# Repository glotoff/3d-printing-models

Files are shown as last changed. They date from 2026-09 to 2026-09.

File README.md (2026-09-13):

# Modular Single-Bay HDD / SSD Caddy (70mm Tall, +10mm Ventilation, Split Guide Pins)

A modular, linkable 3D-printable dock tailored specifically for **$78\text{ mm} \times 14\text{ mm}$ external hard drive / SSD enclosures**, featuring an expanded **$+10\text{ mm}$ ventilation clearance** with **4 internal split cylinder guide pins (7 mm bottom + 7 mm top)** that rigidly constrain the drive while maximizing airflow and reducing print time and plastic consumption.

| Hard Drive Enclosure in Dock (+5mm Air Gap) | 4 Cylinder Pins Inside Bay | 100% Flat Mating Exterior |
| :---: | :---: | :---: |
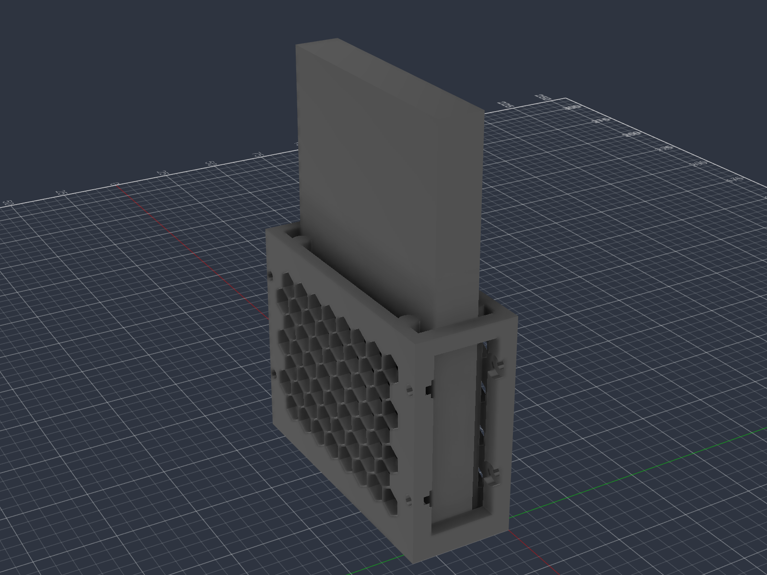
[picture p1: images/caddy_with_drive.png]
Caddy with Drive
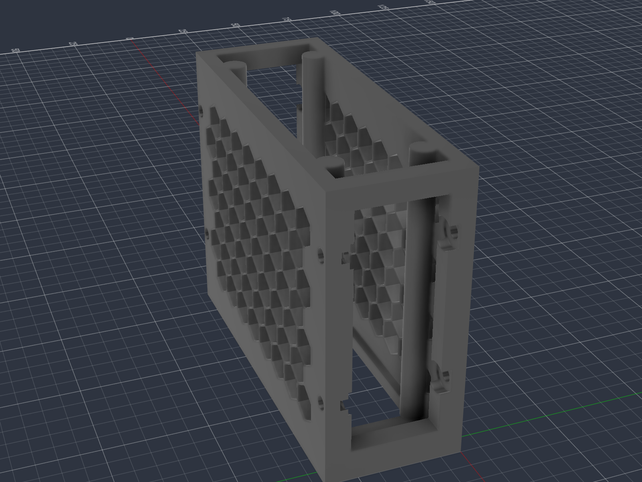
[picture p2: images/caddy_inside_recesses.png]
4 Cylinder Pins Inside
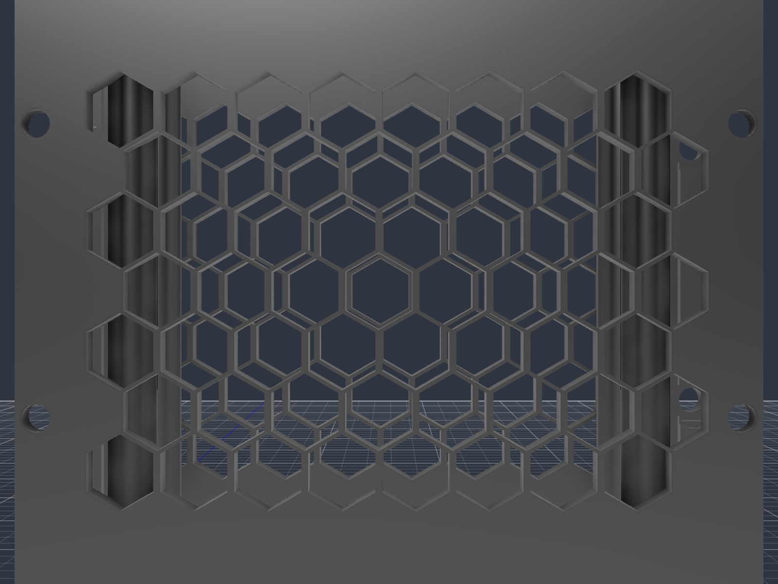
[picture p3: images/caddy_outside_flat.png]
Outside Flat Face
|  |  |  |

---

## Key Features

1. **+10 mm Ventilation Expansion with Split Guide Pins (7 mm Bottom + 7 mm Top):**
   - **Total Slot Width:** Expanded from $14.8\text{ mm}$ to **$24.8\text{ mm}$** (+10 mm) for unrestricted airflow.
   - **Split Cylinder Guide Pins ($\varnothing 6.0\text{ mm}$):**
     - **Bottom Pins:** $7.0\text{ mm}$ tall rising from the floor ($Z = 3.5\text{ mm}$ to $10.5\text{ mm}$) to locate and seat the base of the drive.
     - **Top Pins:** $7.0\text{ mm}$ tall at the top rim ($Z = 63.0\text{ mm}$ to $70.0\text{ mm}$) to guide drive entry and prevent top wobble.
     - **Open Midsection:** The entire middle $52.5\text{ mm}$ is completely open air, cutting print time down to **1h 18m** and filament down to **36.5 g**.
   - **Zero-Wobble Drive Constraint:** The inner tangent distance between the left and right pins is precisely **$14.8\text{ mm}$** ($0.4\text{ mm}$ clearance on each side of the $14.0\text{ mm}$ drive).
   - **Generous 5.0 mm Air Gap on Both Sides:** Rather than resting flush against the honeycomb walls, the drive is held centered with a continuous **$5.0\text{ mm}$ air gap on each side**, allowing massive cross-ventilation across both large aluminium/plastic drive surfaces.

2. **Internal Fastening System (Inside Washer & Nut Recesses):**
   - **Screw Head & Washer Seat (Left Pillar):** $\varnothing 7.5\text{ mm}$ circular counterbore ($2.5\text{ mm}$ deep) on the **inside** face of the pillar ($Y = 6.0\text{ mm}$). Fits standard DIN 125 M3 washers ($\varnothing 7.0\text{ mm}$) and socket/button head screws completely flush inside the vertical window opening.
   - **Captive Hex Nut Pocket (Right Pillar):** $5.6\text{ mm}$ across flats ($2.6\text{ mm}$ deep) with washer recess ($0.8\text{ mm}$ deep) on the **inside** face ($Y = 26.8\text{ mm}$).
   - **100% Flat Exterior Mating Faces:** Both outside walls ($Y = 0$ and $Y = 32.8\text{ mm}$) have **zero counterbores** — only clean $\varnothing 3.4\text{ mm}$ through-holes. When modules are joined side-by-side, their exterior walls mate completely flush with zero gap.
   - **Internal Assembly:** All screws, washers, and nuts are inserted and tightened from **inside** each bay.

3. **Optimized Cross-Ventilation:**
   - Full-height isometric honeycomb lattice (7 rows, 38 mm cell diagonal) on both large side walls for passive cross-ventilation.
   - Bottom chimney through-floor vent ($63.0 \times 20.8\text{ mm}$) for natural convective vertical airflow.

---

## Dimensions Summary

| Parameter | Drive Size | Internal Slot / Pins | External Footprint | Clearance / Tolerance |
| :--- | :---: | :---: | :---: | :--- |
| **Length (X axis)** | **$78.0\text{ mm}$** | **$79.0\text{ mm}$** | **$89.0\text{ mm}$** | $+0.5\text{ mm}$ per end ($1.0\text{ mm}$ total) for smooth insertion |
| **Width / Depth (Y axis)** | **$14.0\text{ mm}$** | **$24.8\text{ mm}$ slot**<br>($14.8\text{ mm}$ between pins) | **$32.8\text{ mm}$** | $+0.4\text{ mm}$ per side between pins; **$5.0\text{ mm}$ air gap** to each wall |
| **Height (Z axis)** | ~125 mm | Open top | **$70.0\text{ mm}$** | High lateral stability |
| **Side Wall Thickness** | — | — | **$4.0\text{ mm}$** | Solid perimeters (4 wall loops) |
| **Floor Thickness** | — | — | **$3.5\text{ mm}$** | Rigid base with chimney vent |
| **Guide Pins** | — | **$4 \times \varnothing 6.0\text{ mm}$ (Split)** | — | **$7.0\text{ mm}$ bottom** + **$7.0\text{ mm}$ top** |
| **Mounting Levels** | — | — | **$Z = 20\text{ mm}$, $Z = 55\text{ mm}$** | Dual screw rigidity |

---

## Multi-Bay Stacking Guide

Modules are daisy-chained side-by-side:

```
       [Bay 1]                  [Bay 2]
+--------------------+   +--------------------+
|  (Inside Bay 1)    |   |  (Inside Bay 2)    |
|                    |   |                    |
|  [Screw + Washer]  |   |    [M3 Hex Nut]    |
|         |          |   |          ^         |
|         +==========>===>==========+         |
|         4mm wall   |   |   4mm wall         |
+--------------------+   +--------------------+
     Flat Mating Joint: 8mm total solid plastic
```

1. Align the flat right exterior wall of Bay 1 with the flat left exterior wall of Bay 2.
2. From **inside Bay 1**, pass an M3 screw with an M3 washer through the inside counterbore.
3. In **inside Bay 2**, thread the screw into the captive M3 hex nut.
4. Tighten with a hex key from inside Bay 1. Both screw head and nut are recessed flush inside the respective window frames, leaving the drive pocket completely clear!

---

## Bill of Materials (BOM) per Joint

To connect two adjacent bays:
- **$2 \times$ M3 Screws:** M3 $\times 12\text{ mm}$ or M3 $\times 14\text{ mm}$ (Socket head DIN 912 or Button head ISO 7380)
- **$2 \times$ M3 Washers:** DIN 125A ($\varnothing 7.0\text{ mm}$ OD, $0.5\text{ mm}$ thickness)
- **$2 \times$ M3 Hex Nuts:** DIN 934 ($5.5\text{ mm}$ across flats)

---

## Slicer & Print Guidelines

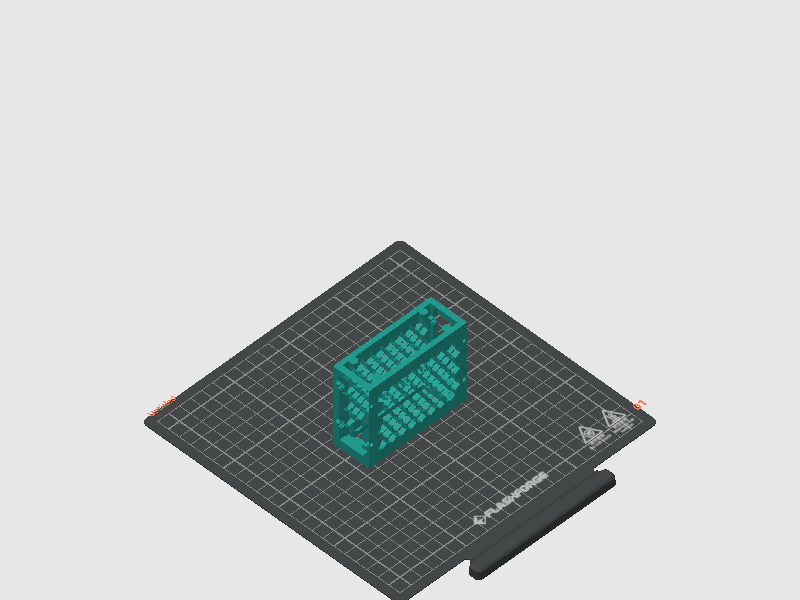
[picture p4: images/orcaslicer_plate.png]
OrcaSlicer Bed Layout


- **Printer:** Flashforge Adventurer 5M Pro / Bambu Lab / Prusa (or any FDM printer)
- **Nozzle:** $0.4\text{ mm}$
- **Layer Height:** $0.20\text{ mm}$
- **Wall Loops:** **4** (ensures 100% solid perimeters through the 4.0 mm walls, guide pins, and around screw holes)
- **Top / Bottom Shells:** 4 layers
- **Infill:** $15\text{--}20\%$ Gyroid
- **Supports:** **None required** (honeycombs, vertical pins, and bridges are 100% self-supporting)
- **Print Time:** ~1h 36m
- **Filament Consumption:** ~43.2 g

---

## Change Tracking in Git (Code-CAD)

Binary 3D models (`.stl`, `.3mf`, `.f3d`) cannot be diffed cleanly in Git. This repository provides text-based parametric models that allow full **Git change tracking**:

1. **OpenSCAD (`cad/modular_single_bay_70mm.scad`):**
   - Pure text-based CSG script.
   - All dimensions (`drive_w`, `drive_t`, `slot_l`, `slot_t`, `caddy_h`, `pin_r`, etc.) are declared as parametric variables at the top of the file.
   - Any modification will produce clear, line-by-line `git diff` outputs.
2. **Fusion 360 Python Generator (`cad/generate_fusion360_model.py`):**
   - Standalone Python script for the Fusion 360 API.
   - Fully parametric generation, appearance assignment, and automated export to STL.
3. **Fusion MCP Client (`cad/fusion_client.py`):**
   - Lightweight JSON-RPC client to execute scripts and export models directly via Fusion 360 MCP.

---

---

## Print Monitoring & Web Dashboard

This repository includes real-time telemetry tools to monitor Flashforge Adventurer 5M series printers via TCP socket (port 8899) and live MJPEG chamber camera stream (port 8080).

### 1. CLI Monitor (`print_status.py`)
Quick command-line tool for checking temperatures, layer count, file, and progress:
```bash
python print_status.py          # One-time status snapshot
python print_status.py --watch  # Auto-refreshing terminal HUD (every 5s)
```

### 2. Real-Time Web Dashboard (`app/`)
A responsive dark-themed dashboard containerized with Docker and deployed to `kopilka:4000`:
- **Live Chamber Camera Feed:** Embedded low-latency MJPEG stream with real-time XYZ toolhead coordinate overlay.
- **WebSocket Telemetry:** Zero-latency updates for Nozzle & Bed temperatures (actual vs. target), layer progress (`Layer X / Y`), elapsed time, and extruded filament length (A).
- **Printer Controls:** Remote chamber LED light toggle (`~M651` / `~M652`) and Pause / Resume controls (`~M25` / `~M24`).
- **Stream Recording & Archive:** Direct server-side recording of the camera feed into compressed H.264 MP4 clips via FFmpeg, with a built-in gallery for downloads and management.
- **Access:** Available on local network at `http://kopilka:4000/`.

To run locally or deploy:
```bash
cd app
docker compose up -d --build
```

---

---

## Fresh Laptop Setup Guide (Zero to Ready)

If you clone this repository onto a brand-new computer, here is exactly what to install and how to work with the project files:

### 1. Requirements Checklist

| Software / Tool | Purpose | How to Get |
| :--- | :--- | :--- |
| **Git** | Cloning & updating the repository | [git-scm.com](https://git-scm.com/) |
| **Python 3.10+** | CLI telemetry scripts & running the local web app | [python.org](https://www.python.org/) or `winget install Python.Python.3.12` |
| **OrcaSlicer (v2.x+)** | Slicing models & sending prints to Flashforge / Klipper | [github.com/SoftFever/OrcaSlicer/releases](https://github.com/SoftFever/OrcaSlicer/releases) |
| **Autodesk Fusion 360** *(Optional for CAD editing)* | Inspecting or modifying the native parametric model | [autodesk.com/products/fusion-360](https://www.autodesk.com/products/fusion-360/personal) |
| **Docker Desktop** *(Optional for telemetry web dashboard)* | Containerized web dashboard deployment | [docker.com](https://www.docker.com/) |

---

### 2. Workflow: 3D Printing (Ready Out of the Box)

You do **not** need CAD software installed just to slice or print:

1. **Clone the repository:**
   ```bash
   git clone https://github.com/glotoff/3d-printing-models.git
   cd 3d-printing-models
   ```
2. **Open in OrcaSlicer:**
   - Double-click [`Modular_SingleBay_16mm_M3.3mf`](Modular_SingleBay_16mm_M3.3mf).
   - This opens the exact project with all tuned print settings:
     - 4 wall loops (1.6 mm solid shell)
     - 15% infill
     - 0.20 mm layer height
     - Flashforge Adventurer 5M Pro profile
   - Click **Slice plate** and send directly to your printer over Wi-Fi.
3. **Alternatively, use the pre-sliced G-code directly:**
   - [`Modular_SingleBay_SplitPins_7mm_PLA_1h18m.gcode`](Modular_SingleBay_SplitPins_7mm_PLA_1h18m.gcode) can be loaded directly onto a USB stick or uploaded via Flashforge web UI.

---

### 3. Workflow: CAD Modeling & Editing in Autodesk Fusion 360

If you want to edit, customize, or export variations in Fusion 360:

#### Option A: Open the Standalone `.f3d` Archive (Easiest)
1. Open **Autodesk Fusion 360**.
2. Click **File** $\to$ **Open...** $\to$ **Open from my computer**.
3. Select [`cad/Modular_SingleBay_Vent10mm_SplitPins.f3d`](cad/Modular_SingleBay_Vent10mm_SplitPins.f3d).
4. All bodies (caddy body and hard drive reference mock-up) and geometry will load natively.

#### Option B: Import the Universal `.step` File
- In Fusion 360 (or FreeCAD / SolidWorks), go to **File** $\to$ **Open** $\to$ select [`cad/Modular_SingleBay_Vent10mm_SplitPins.step`](cad/Modular_SingleBay_Vent10mm_SplitPins.step).

#### Option C: Re-generate From Python Script (Parametric Automation)
1. In Fusion 360, press **Shift + S** to open the **Scripts and Add-Ins** window.
2. Under the **Scripts** tab, click the green **+** icon (Create / Add).
3. Select or paste the contents of [`cad/generate_fusion360_model.py`](cad/generate_fusion360_model.py).
4. Click **Run**. The script will automatically generate the 3D model, apply all cutouts and split guide pins, insert the hard drive verification body, and export the high-res STL mesh.

---

### 4. Workflow: Printer Monitoring & Telemetry

1. **Instant CLI Status:**
   ```bash
   pip install requests
   python print_status.py          # One-shot terminal status snapshot
   python print_status.py --watch  # Auto-refreshing HUD (every 5s)
   ```

2. **Web Monitoring App (Local or Docker):**
   - **Running locally with Python:**
     ```bash
     cd app
     pip install -r requirements.txt
     python -m uvicorn main:app --host 0.0.0.0 --port 4000
     ```
   - **Running with Docker:**
     ```bash
     cd app
     docker compose up -d --build
     ```
   - Open your browser to `http://localhost:4000/`.

---

## Repository Structure

```
.
├── app/                                            # Real-time web telemetry dashboard
│   ├── Dockerfile
│   ├── docker-compose.yml
│   ├── main.py                                     # FastAPI + WebSocket backend & camera proxy
│   ├── requirements.txt
│   └── templates/
│       └── index.html                              # Dark-mode dashboard with Tailwind CSS
├── cad/
│   ├── Modular_SingleBay_Vent10mm_SplitPins.f3d   # Standalone native Autodesk Fusion 360 archive
│   ├── Modular_SingleBay_Vent10mm_SplitPins.step  # Universal CAD solid exchange model
│   └── generate_fusion360_model.py                 # Parametric Fusion 360 API generator
├── models/
│   └── Modular_SingleBay_70mm_Tight.stl            # Production STL model (89.0 x 32.8 x 70.0 mm)
├── Modular_SingleBay_SplitPins_7mm_PLA_1h18m.gcode # Print-ready G-code (Adventurer 5M Pro)
├── Modular_SingleBay_16mm_M3.3mf                   # OrcaSlicer complete project file
├── print_status.py                                 # CLI printer telemetry script
├── images/                                         # 3D viewport renders and slicer plate previews
├── legacy/                                         # Previous prototype iterations and test models
├── .gitignore
└── README.md
```

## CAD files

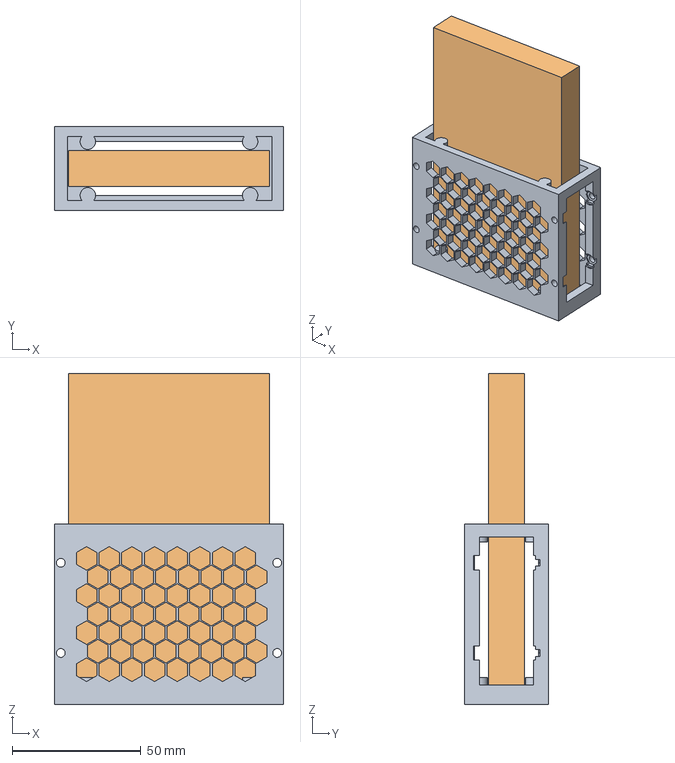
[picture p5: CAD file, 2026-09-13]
cad/Modular_SingleBay_Vent10mm_SplitPins.step
89.0 x 32.8 x 128.5 mm

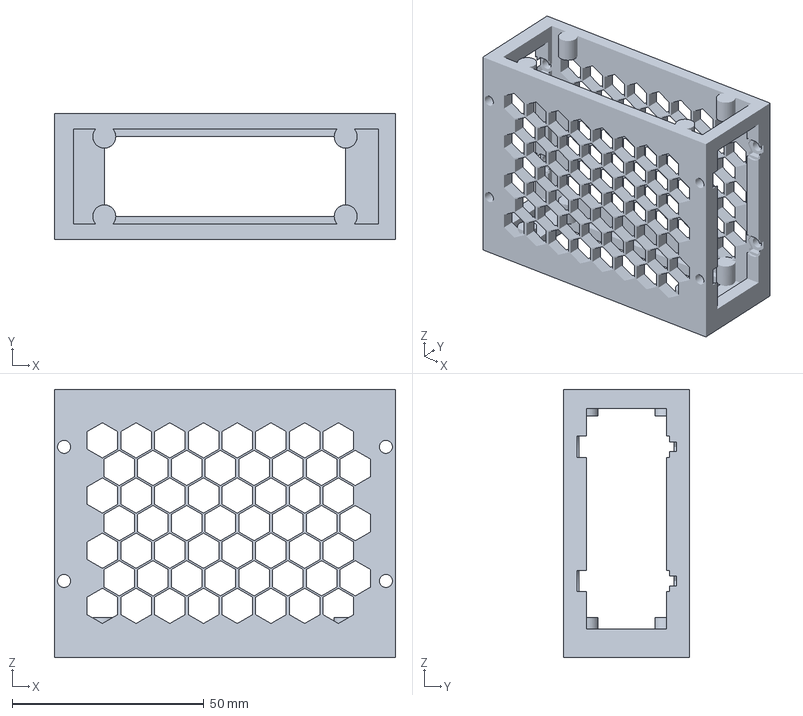
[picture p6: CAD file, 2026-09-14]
Modular_SingleBay_16mm_M3.3mf
89.0 x 32.8 x 70.0 mm

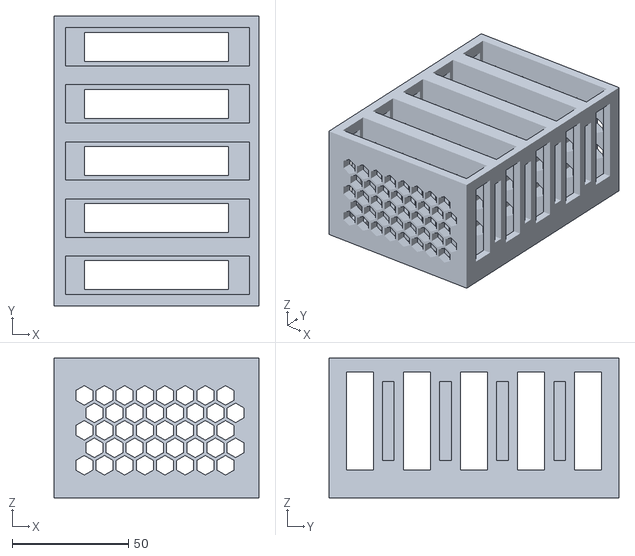
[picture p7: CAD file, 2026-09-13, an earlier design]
legacy/Design2_Honeycomb_Toaster.stl
88.0 x 124.5 x 60.0

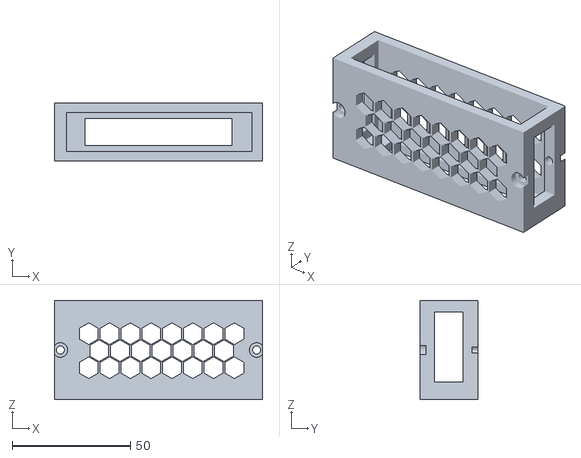
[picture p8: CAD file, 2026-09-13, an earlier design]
legacy/Modular_Honeycomb_M3.stl
88.0 x 24.5 x 42.0

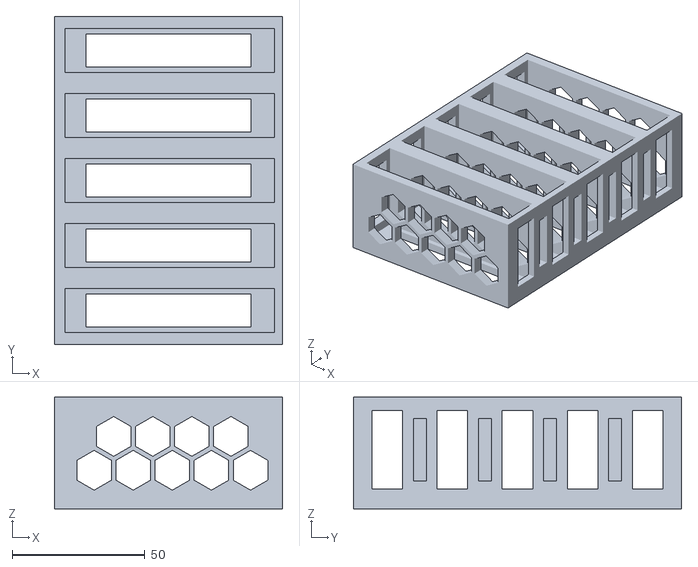
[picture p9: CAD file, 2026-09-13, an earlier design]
legacy/Design2_FastPrint_Toaster.stl
86.0 x 123.5 x 42.0

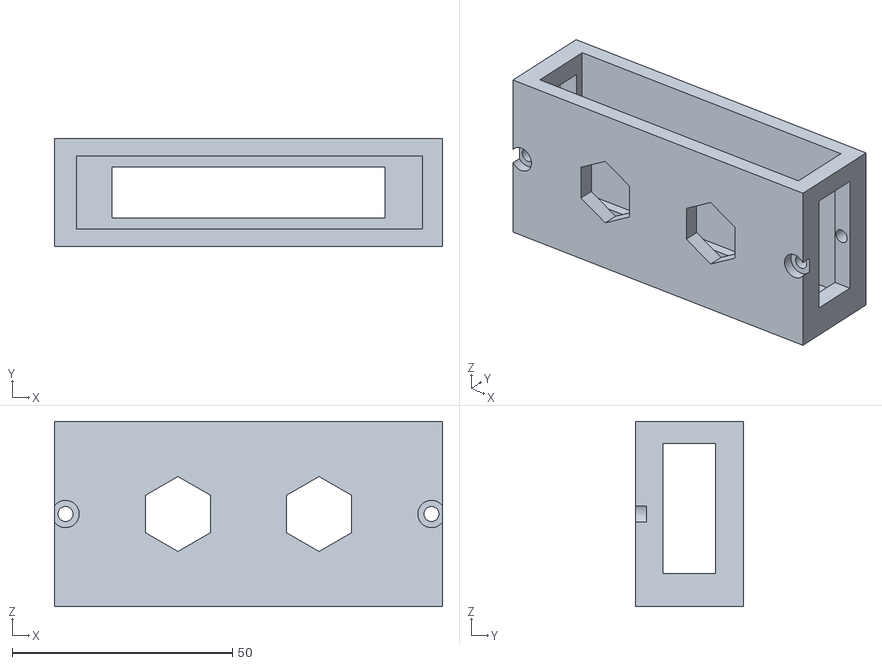
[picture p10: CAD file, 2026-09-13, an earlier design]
legacy/Modular_SingleBay_M3.stl
88.0 x 24.5 x 42.0

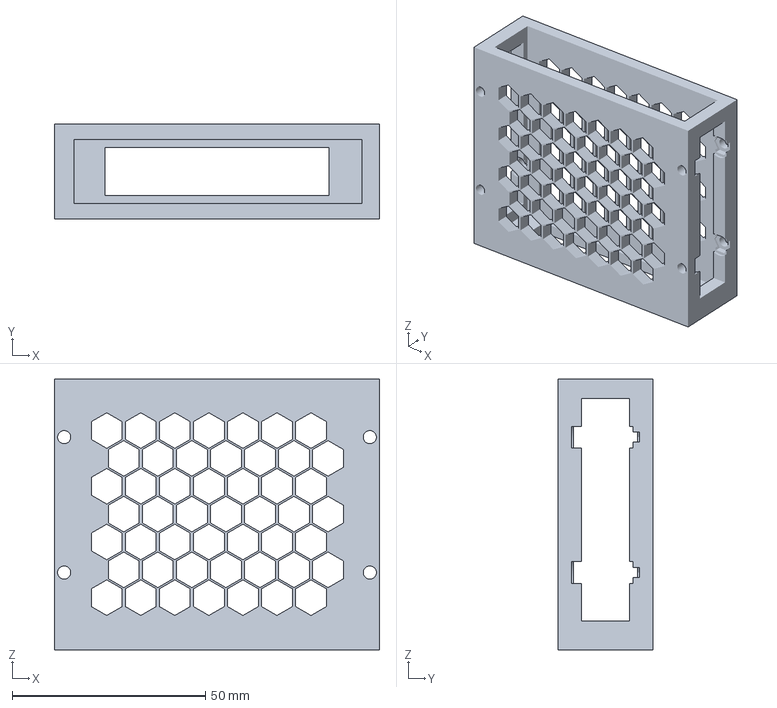
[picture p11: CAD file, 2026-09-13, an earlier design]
legacy/Modular_SingleBay_16mm_M3.3mf
84.0 x 24.5 x 70.0 mm

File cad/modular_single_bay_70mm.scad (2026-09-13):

// ==============================================================================
// Modular Single-Bay HDD / SSD Caddy (70mm Tall, +10mm Vent, 4 Guide Pins)
// Parametric OpenSCAD Model for Git Version Control and Change Tracking
// ==============================================================================

$fn = 60;

// --- PARAMETERS (All dimensions in mm) ---

// Hard Drive Dimensions
drive_w         = 78.0;  // Drive width (X axis)
drive_t         = 14.0;  // Drive depth / thickness (Y axis)
drive_h         = 125.0; // Drive upright height (Z axis)

// Internal Slot Dimensions (+10 mm ventilation expansion)
slot_l          = 79.0;  // Internal slot length (X axis) - 0.5mm clearance each end
slot_t          = 24.8;  // Internal slot width (Y axis) - expanded for +10mm airflow
caddy_h         = 70.0;  // Total height (Z axis)
wall_t          = 4.0;   // Solid side wall thickness (Y axis)
base_t          = 3.5;   // Bottom floor thickness (Z axis)
front_lip       = 5.0;   // Solid front pillar length (X axis)
rear_lip        = 5.0;   // Solid rear pillar length (X axis)

// Retaining Lips & Windows
lip_t           = 2.0;   // Front/rear retaining lip width on each side
window_z_bot    = 7.5;   // Window bottom Z coordinate
window_z_top    = 65.0;  // Window top Z coordinate

// Derived Module Dimensions
mod_w           = slot_t + 2 * wall_t;           // 32.8 mm total width (+10mm)
mod_l           = slot_l + front_lip + rear_lip; // 89.0 mm total length
window_w        = slot_t - 2 * lip_t;            // 20.8 mm window opening width

// 4 Guide Pin Parameters (Constrains 14.0mm drive with 5.0mm air gap on each side)
pin_r           = 3.0;   // 6.0 mm diameter cylinder pins
y_pin_left      = wall_t + lip_t;                // 6.0 mm (tangent at 9.0 mm)
y_pin_right     = wall_t + slot_t - lip_t;       // 26.8 mm (tangent at 23.8 mm)
// Clearance between pin tangents: 23.8 - 9.0 = 14.8 mm (0.4mm clearance per side)
x_pin_front     = front_lip + 8.0;               // 13.0 mm
x_pin_rear      = front_lip + slot_l - 8.0;      // 76.0 mm

// M3 Joining Hardware Parameters
z_screws        = [20.0, 55.0]; // Dual mounting hole heights
x_screw_front   = front_lip / 2.0;               // 2.5 mm
x_screw_rear    = front_lip + slot_l + rear_lip / 2.0; // 86.5 mm
m3_hole_dia     = 3.4;   // Clearance through-hole diameter
m3_washer_dia   = 7.5;   // Inside counterbore diameter (for DIN 125 washer + screw head)
m3_washer_depth = 2.5;   // Inside counterbore depth
m3_nut_f2f      = 5.6;   // Captive hex nut pocket width across flats
m3_nut_depth    = 2.6;   // Captive hex nut pocket depth
nut_washer_depth= 0.8;   // Inside washer recess on nut side

// Honeycomb Lattice Parameters
hex_r           = 4.6;   // Hexagon circumradius
hex_dx          = 8.8;   // Horizontal column spacing
hex_dz          = 7.2;   // Vertical row spacing

// --- MODULES ---

module hexagon(r, h) {
    cylinder(r = r, h = h, center = true, $fn = 6);
}

module hex_nut_pocket(f2f, depth) {
    r = f2f / sqrt(3);
    cylinder(r = r, h = depth, $fn = 6);
}

module caddy_body() {
    difference() {
        // 1. Solid Outer Block + 4 Guide Pins
        union() {
            cube([mod_l, mod_w, caddy_h]);
            
            // 4 Vertical Cylinder Pins (extending from floor to top)
            for (xp = [x_pin_front, x_pin_rear]) {
                for (yp = [y_pin_left, y_pin_right]) {
                    translate([xp, yp, base_t])
                        cylinder(r = pin_r, h = caddy_h - base_t);
                }
            }
        }

        // 2. Drive Slot Pocket
        translate([front_lip, wall_t, base_t])
            cube([slot_l + 0.1, slot_t, caddy_h + 1]);

        // 3. Bottom Chimney Vent (through floor)
        translate([front_lip + 8.0, wall_t + lip_t, -1])
            cube([slot_l - 16.0, slot_t - 2 * lip_t, base_t + 2]);

        // 4. Front Vertical Window
        translate([-1, wall_t + lip_t, window_z_bot])
            cube([front_lip + 2, window_w, window_z_top - window_z_bot]);

        // 5. Rear Vertical Window
        translate([front_lip + slot_l - 1, wall_t + lip_t, window_z_bot])
            cube([rear_lip + 2, window_w, window_z_top - window_z_bot]);

        // 6. Honeycomb Lattice on Side Walls (7 rows)
        for (row = [0:6]) {
            z_c = 13.5 + row * hex_dz;
            x_shift = (row % 2 == 1) ? (hex_dx / 2.0) : 0.0;
            for (col = [0:8]) {
                x_c = front_lip + 7.5 + col * hex_dx + x_shift;
                if (x_c >= (front_lip + 5.5) && 
                    x_c <= (front_lip + slot_l - 5.5) && 
                    (z_c + hex_r) <= (caddy_h - 4.5)) {
                    translate([x_c, -1, z_c])
                        rotate([-90, 0, 0])
                        hexagon(hex_r, mod_w + 2);
                }
            }
        }

        // 7. M3 Joining System in Solid Pillars
        for (zs = z_screws) {
            for (xs = [x_screw_front, x_screw_rear]) {
                // A. M3 Through-Hole (3.4 mm) across entire width
                translate([xs, -1, zs])
                    rotate([-90, 0, 0])
                    cylinder(d = m3_hole_dia, h = mod_w + 2);

                // B. Inside Washer / Screw Head Counterbore (Left Pillar)
                // Inside face of left pillar is at Y = wall_t + lip_t (6.0 mm)
                // Cuts outward (towards -Y) by 2.5 mm (down to Y = 3.5 mm).
                // Outer face at Y = 0 remains 100% FLAT with 3.5 mm solid wall!
                translate([xs, wall_t + lip_t - m3_washer_depth, zs])
                    rotate([-90, 0, 0])
                    cylinder(d = m3_washer_dia, h = m3_washer_depth + 0.1);

                // C. Inside Hex Nut Pocket (Right Pillar)
                // Inside face of right pillar is at Y = wall_t + slot_t - lip_t (26.8 mm)
                // Cuts outward (towards +Y) by 2.6 mm (up to Y = 29.4 mm).
                // Outer face at Y = 32.8 mm remains 100% FLAT with 3.4 mm solid wall!
                translate([xs, wall_t + slot_t - lip_t - 0.05, zs])
                    rotate([-90, 0, 0])
                    hex_nut_pocket(m3_nut_f2f, m3_nut_depth + 0.1);

                // D. Inside Washer Recess on Nut Side
                translate([xs, wall_t + slot_t - lip_t - 0.05, zs])
                    rotate([-90, 0, 0])
                    cylinder(d = m3_washer_dia, h = nut_washer_depth + 0.1);
            }
        }
    }
}

// Render the single bay
caddy_body();

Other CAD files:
Modular_SingleBay_70mm_Tight.stl
cad/Modular_SingleBay_Vent10mm_SplitPins.f3d
legacy/Modular_SingleBay_16mm_M3.stl
models/Modular_SingleBay_70mm_Tight.stl

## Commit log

2026-09-13 Initial commit: Modular 70mm Single-Bay HDD Caddy with inside washer recesses and Code-CAD models
    [Design2_FastPrint_Toaster.stl, Design2_Honeycomb_Toaster.stl, Modular_Honeycomb_M3.stl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]
2026-09-13 Update dimensions to exact fit for 78x14mm drive (slot 79.0x14.8mm, outer 89.0x22.8x70mm)
    [Modular_SingleBay_70mm_Tight.stl, modular_single_bay_70mm.scad]
2026-09-13 Update README with 78x14mm specifications, add new renders with drive, and sync OrcaSlicer project
    [Modular_SingleBay_16mm_M3.3mf, Modular_SingleBay_70mm_Tight.stl]
2026-09-13 Expand depth by +10mm for enhanced ventilation with 4 internal vertical cylinder guide pins
    [Modular_SingleBay_70mm_Tight.stl, modular_single_bay_70mm.scad]
2026-09-13 docs: enhance README with multi-bay stacking guide and sync OrcaSlicer project
    [Modular_SingleBay_16mm_M3.3mf]
2026-09-13 feat: add CLI print progress and telemetry monitor for Flashforge printer
2026-09-13 fix(monitor): fix null ref in WebSocket updateUI and improve LED toggle reactivity
2026-09-13 feat(caddy): split guide pins into 7mm bottom and 7mm top guides
    - Update Fusion 360 script to split the 4 guide pins into 7mm floor-mounted and 7mm top-mounted pins
    - Save active document as 14_Modular_SingleBay_Vent10mm_SplitPins in Fusion 360
    - Re-slice in OrcaSlicer: print time dropped from 1h 36m to 1h 18m, filament reduced to 36.5g
    - Export Modular_SingleBay_SplitPins_7mm_PLA_1h18m.gcode
    - Document split guide pins and performance savings in README.md
    [Modular_SingleBay_16mm_M3.3mf, Modular_SingleBay_70mm_Tight.stl]
2026-09-13 chore(orcaslicer): save updated project state after slice
    [Modular_SingleBay_16mm_M3.3mf]
2026-09-13 feat(cad): export standalone F3D and STEP models and add fresh laptop guide
    - Export native Autodesk Fusion 360 archive (.f3d) and STEP (.step) models
    - Add comprehensive 'Fresh Laptop Setup Guide' to README.md covering:
    - 3D printing workflow with OrcaSlicer and pre-sliced G-code
    - CAD modeling & modification workflow (F3D, STEP, Python API)
    - Telemetry and web dashboard setup (CLI, Python, Docker)
    - Update repo tree diagram
    [Modular_SingleBay_Vent10mm_SplitPins.f3d, Modular_SingleBay_Vent10mm_SplitPins.step]
2026-09-13 feat(slicer): add 3x overnight multi-item print G-code (3h 52m, 109g)
    - 3 identical Modular_SingleBay_70mm_Tight units arranged side-by-side on Flashforge AD5M Pro bed
    - Sliced with 0.20mm Standard profile, 4 wall loops, 15% infill
    - Print time: 3 hours 51 minutes 41 seconds
    - Total filament: 109.5g PLA
2026-09-13 feat(slicer): add 2-bay overnight print G-code (2h 35m, 73.0g PLA)
2026-09-14 fix(app): update printer IP to 192.168.50.99 and add recording validation feedback
    [Modular_SingleBay_16mm_M3.3mf]
2026-09-14 feat(app): fix chamber LED toggle with M146 RGB sequence and add printer sleep/power-off control
